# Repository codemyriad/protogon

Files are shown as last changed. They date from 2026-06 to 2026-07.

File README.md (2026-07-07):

# Protogon

The protogon is a prototyping board for the EMF Tildagon and Spaceagon badges.
If you don't understand what this means, it probably means that this project is not useful to you. But feel free to go down the rabbit hole!

* 64 kiB EEPROM
* EEPROM write protection jumper (P1) sort is write protected
* Qwiic connector
* I2c pull ups
* Power LED
* max 3v3 current: 600mA

Protogon, top side

It can be used to prototype a hexpansion. It features EEPROM (with write-protect jumper) and Qwiic connections.

The idea is based on JakeW's [protoboard hexpansion](https://www.tindie.com/products/jakew/protoboard-hexpansion/).

The board fits a 64 kbit EEPROM. There's a jumper you can short to write protect the EEPROM.
A connector is available to plug in Qwiic/STEMMA QT compatible sensors.

Even when not populated with components the board can be used for a basic hexpansion. The EEPROM is quite a valuable bit to mount, since the badge can recognize the hexpansion and load its code.

## Using files in the repo

The KiCad files are in the root: `codemyriad-protogon.kicad_*`.
The `fabrication/codemyriad-protogon-fab.zip` file is ready to upload to produce the board through a PCB manufacturing service. Make sure you select 1.0 mm FR4 and ENIG finish!
`fabrication/bom-lcsc.csv` contains a Bill Of Materials with LCSC codes.

## Credits

* Many thanks to **JakeW** for the [Protoboard Hexpansion](https://www.tindie.com/products/jakew/protoboard-hexpansion/). The idea for this board came from seeing his one.
* **EMF Camp** for the badge, the hexpansion spec, and the [KiCad template](https://github.com/emfcamp/badge-2024-hardware). This work is based on those KiCad files.

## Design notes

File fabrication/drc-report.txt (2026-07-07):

** Drc report for codemyriad-protogon.kicad_pcb **
** Created on 2026-07-07T11:46:43+0200 **
** Report includes: Errors **

** Found 0 DRC violations **

** Found 0 unconnected pads **

** Found 0 Footprint errors **

** End of Report **

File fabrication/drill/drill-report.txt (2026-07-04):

Drill report for codemyriad-protogon.kicad_pcb
Created on 2026-07-04T14:08:01+0200

Copper Layer Stackup:
    =============================================================
    L1 :  F.Cu                      front
    L2 :  B.Cu                      back

Drill file 'codemyriad-protogon-PTH.drl' contains
    plated through holes:
    =============================================================
    T1  0.300mm  0.0118"  (1 hole)
    T2  0.400mm  0.0157"  (9 holes)
    T3  0.400mm  0.0157"  (16 holes)
    T4  1.000mm  0.0394"  (140 holes)
    T5  1.200mm  0.0472"  (2 holes)
    T6  2.200mm  0.0866"  (2 holes)

    Total plated holes count 170

Drill file 'codemyriad-protogon-NPTH.drl' contains
    unplated through holes:
    =============================================================

    Total unplated holes count 0

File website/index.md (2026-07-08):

# A prototyping board to build your hexpansion

The protogon board

Features:

* 64 Kbit (8 KiB) EEPROM
* EEPROM write protection jumper (P1): short it to write-protect
* Qwiic connector
* I2C pull-ups
* Power LED
* max 3V3 current: 600 mA

## Parts to solder

* `R1`: one 402 Ω resistor
* `R2`, `R3` and `R4`: three 4.7 kΩ resistors
* `C1`: a 0.1 µF capacitor
* `D1`: an LED
* `U1`: a 64 Kbit EEPROM
* `U2`: a Qwiic connector

We missed a mark on the board. This is the correct LED polarity:

Close-up of D1: the bar of the diode symbol marks the cathode, on the GND side

## Online code editor for badge apps

We extended (vibe coded) the [badge emulator](https://emulator.badge.emfcamp.org/) and added a code editor.
[You can try live coding your badge app here](https://protogon.codemyriad.io/editor)

## Github repository

See https://github.com/codemyriad/protogon for source KiCad files and more

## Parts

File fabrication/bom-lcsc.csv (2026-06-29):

Designator | Footprint | Quantity | Value | LCSC Part #
C1 | 0603 | 1 | 0.1uF | C1591
D1 | 0805 | 1 | LED | C19171391
H1, H2 | MountingHole_2.2mm_M2_Pad_Via | 2 | MountingHole_Pad
J2 | PinHeader_2x10_P2.54mm_Vertical | 1 | Conn_02x10_Odd_Even | C492427
P1 | HDR-TH_2P-P2.54-V-M | 1 | PZ254V-11-02P | C492401
PROTO1 |  | 1 | integrated 10x14 protoboard grid
R1 | 0603 | 1 | 402 | C2930100
R2, R3, R4 | 0603 | 3 | 4K7 | C105428
U1 | TSSOP-8_L4.4-W3.0-P0.65-LS6.4-BL | 1 | ZD24C64A-XGMT | C2875852
U2 | CONN-SMD_4P-P1.00_SM04B-SRSS-TB-LF-SN | 1 | SM04B-SRSS-TB_(LF)(SN) | C160404

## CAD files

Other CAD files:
fabrication/step/codemyriad-protogon.step

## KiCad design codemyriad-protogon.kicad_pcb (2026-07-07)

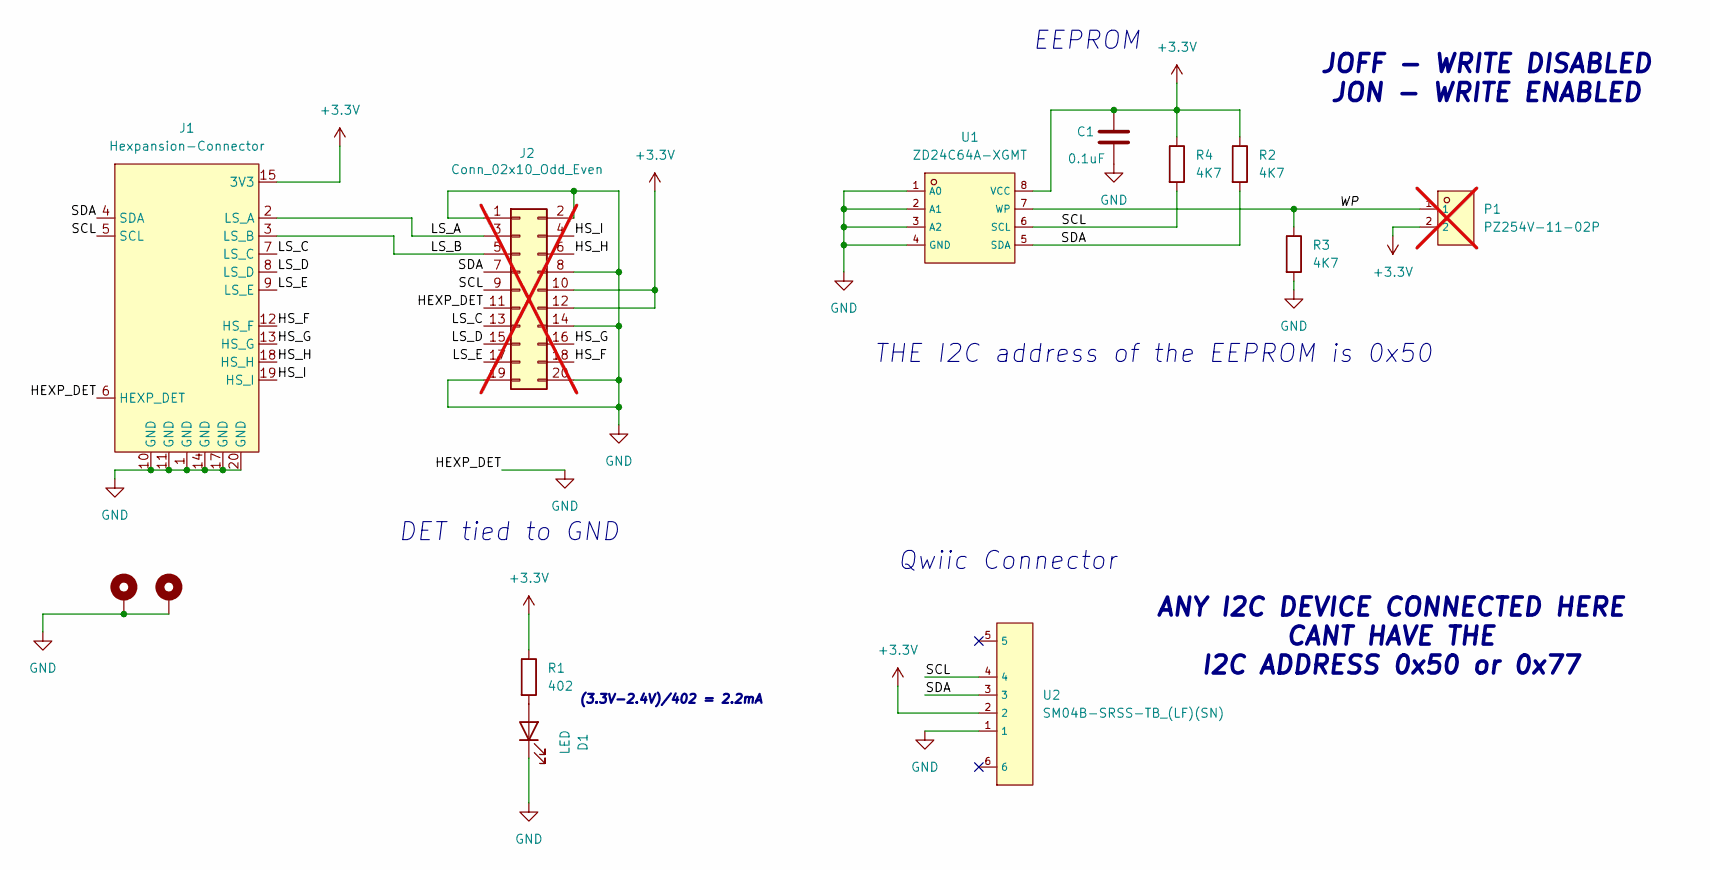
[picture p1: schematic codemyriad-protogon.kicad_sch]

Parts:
C1: 0.1uF; C_0603_1608Metric_Pad1.08x0.95mm_HandSolder; LCSC C1591
D1: LED; LED_0805_2012Metric; LCSC C19171391
H1, H2: MountingHole_Pad; MountingHole_2.2mm_M2_Pad_Via
J1: Hexpansion-Connector; hexpansion-edge-connector
J2: Conn_02x10_Odd_Even; PinHeader_2x10_P2.54mm_Vertical; LCSC C492427; not fitted
P1: PZ254V-11-02P; HDR-TH_2P-P2.54-V-M; LCSC C492401; not fitted
R1: 402; R_0603_1608Metric; LCSC C2930100
R2, R3, R4: 4K7; R_0603_1608Metric_Pad0.98x0.95mm_HandSolder; LCSC C105428
U1: ZD24C64A-XGMT; TSSOP-8_L4.4-W3.0-P0.65-LS6.4-BL; LCSC C2875852
U2: SM04B-SRSS-TB_(LF)(SN); CONN-SMD_4P-P1.00_SM04B-SRSS-TB-LF-SN; LCSC C160404

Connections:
+3.3V: C1.1, J1.15 (3V3), J1.16 (3V3), J2.10, J2.12, P1.2, R1.1, R2.1, R4.1, U1.8 (VCC), U2.2; also elsewhere on the board
/HS_F: J1.12 (HS_F), J2.18
/HS_G: J1.13 (HS_G), J2.16
/HS_H: J1.18 (HS_H), J2.6
/HS_I: J1.19 (HS_I), J2.4
/LS_A: J1.2 (LS_A), J2.3
/LS_B: J1.3 (LS_B), J2.5
/LS_C: J1.7 (LS_C), J2.13
/LS_D: J1.8 (LS_D), J2.15
/LS_E: J1.9 (LS_E), J2.17
/SCL: J1.5 (SCL), J2.9, R4.2, U1.6 (SCL), U2.4
/SDA: J1.4 (SDA), J2.7, R2.2, U1.5 (SDA), U2.3
/WP: P1.1, R3.1, U1.7 (WP)
GND: C1.2, D1.1 (K), H1.1, H2.1, J1.1 (GND), J1.6 (HEXP_DET), J1.10 (GND), J1.11 (GND), J1.14 (GND), J1.17 (GND), J1.20 (GND), J2.1, J2.2, J2.8, J2.11, J2.14, J2.19, J2.20, R3.2, U1.1 (A0), U1.2 (A1), U1.3 (A2), U1.4 (GND), U2.1; also elsewhere on the board
unnamed: D1.2 (A), R1.2

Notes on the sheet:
Qwiic Connector
(3.3V-2.4V)/402 = 2.2mA
DET tied to GND
EEPROM
JOFF - WRITE DISABLED JON - WRITE ENABLED
THE I2C address of the EEPROM is 0x50
ANY I2C DEVICE CONNECTED HERE CANT HAVE THE I2C ADDRESS 0x50 or 0x77

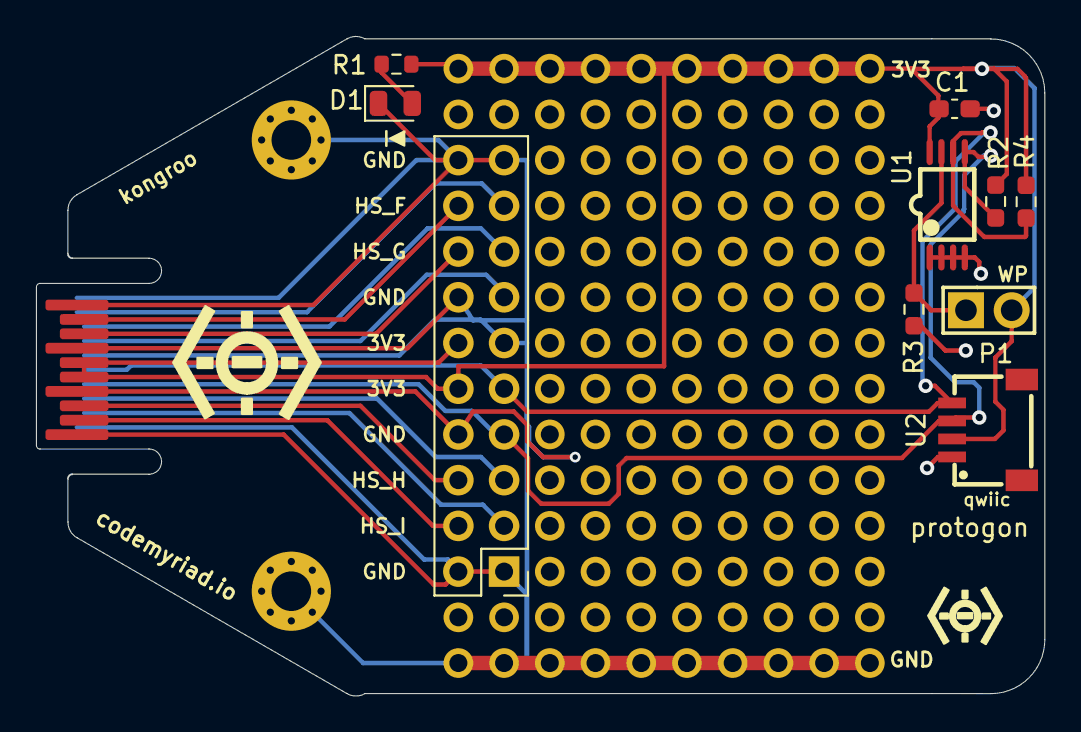
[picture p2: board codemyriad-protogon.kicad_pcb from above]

Board: 2 copper layers, 56.0 x 36.6 mm, 14 parts (0 on the bottom side), 15 nets.

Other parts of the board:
PROTO1: integrated 10x14 protoboard grid

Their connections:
+3.3V: PROTO1.1, PROTO1.2, PROTO1.3, PROTO1.4, PROTO1.5, PROTO1.6, PROTO1.7, PROTO1.8, PROTO1.9, PROTO1.10; also elsewhere on the board
GND: PROTO1.111, PROTO1.112, PROTO1.113, PROTO1.114, PROTO1.115, PROTO1.116, PROTO1.117, PROTO1.118, PROTO1.119, PROTO1.120; also elsewhere on the board

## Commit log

2026-06-22 Initial commit: Code Myriad Protogon hexpansion + order prep
    Bare protoboard hexpansion for the EMF 2024 Tildagon / 2026 Spaceagon badge,
    plus the cost research used to decide how/where to order the giveaway run.
    - codemyriad-protogon/: KiCad design (DRC clean), fabrication/ Gerber+drill
    order zip, STEP model, and renders
    - tools/: generate_protogon.py (generates the .kicad_pcb -- the source of
    truth) and render_protogon_blender.py
    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
    [codemyriad-protogon-B_Cu.gbl, codemyriad-protogon-B_Mask.gbs, codemyriad-protogon-B_Silkscreen.gbo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]
2026-06-22 Add Cycles GPU render path + one-command remote-render workflow
    Accurate, GPU-accelerated renders for the giveaway visuals.
    - render_protogon_blender.py: new --engine cycles (OptiX/CUDA path tracing on
    the GPU, auto backend selection with CPU fallback). Denoises with
    OpenImageDenoise by default because the OptiX denoiser fails to initialise on
    some driver/GPU combos (observed on RTX 5060 / Blackwell + Blender 4.5);
    path tracing still runs on the GPU. Adds per-engine sample defaults
    (8 eevee / 128 cycles), --gpu-backend, --denoiser, and --poster-only.
    - tools/render-on-roy.sh: rsync the repo to a GPU box, render the loop with
    Cycles/OptiX, and sync poster/MP4/GIF/contact back int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
2026-06-22 Audit follow-ups: fix width field + document board regeneration
    - QUOTE-RECIPE.json: correct outline_bbox width 48.0 -> 49.75 mm (the 48.0 omitted
    the J1 connector tab; 49.75 matches the fab-detected size both quotes used) and
    annotate why.
    - README: document the regenerate-from-clean prerequisites for the source-of-truth
    board -- the gitignored upstream clone (pinned) and KiCad's pcbnew module -- plus
    the generate + fab re-export steps.
2026-06-22 Regenerate loop renders with Cycles/OptiX (GPU, photoreal)
    Replaces the EEVEE turntable loop with a Cycles path-traced version rendered on
    the RTX 5060 (roy.wye.it): 96 frames, 1280x720, 128 spp, OpenImageDenoise.
    Accurate ENIG gold, matte black soldermask, and real shadows. Poster, MP4, GIF
    (stride-2 / 12.5 fps, judder-free) and contact sheet all regenerated.
2026-06-22 Render the real board geometry (truthful) instead of flat decals
    The loop was painting the artwork as self-lit 2D "decal" planes floating over a
    featureless slab, which made it untruthful: flat unlit gold, copper-vs-gold pad
    mismatch, fake holes, no thickness, a back face mis-oriented 90deg, and a squared
    hexagon corner. Switch to rendering the actual GLB geometry (copper/pads/vias/
    silkscreen/soldermask/body) with lit PCB materials, so it's one real 3D object.
    - render_protogon_blender.py: real ENIG gold (metallic, satin), semi-gloss black
    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
2026-06-22 Fix camera near-clip slicing the board; slow the loop to 8s
    - render_protogon_blender.py: set scale-relative ORTHO camera clip planes
    (clip_start = max_dim*0.1, clip_end = max_dim*10). The default 0.1m near clip
    was slicing whichever hexagon corner swung closest to the camera, which read
    as the board being clipped to a bounding cube. Verified clean at all angles.
    - Slow the turntable: default loop 96 -> 192 frames at 24 fps (4s -> 8s/rev),
    same smoothness; GIF stride-2 decimation stays exact (192 even). Updated the
    render-on-roy.sh default and the README loop math.
    - Regenerated poster/MP4/GIF/contact (192f, 1280x720, 128 spp, RTX 5060).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
2026-06-22 Add --xray render mode (translucent soldermask) to inspect copper routing
    On a real black-soldermask board the J1->J2 breakout traces are buried under the
    opaque mask and aren't visible -- only exposed gold pads and white silk show.
    --xray drops the soldermask to ~15% opacity so the copper routing shows through,
    for design inspection (not a truthful product shot). material() gains an `alpha`
    arg; apply_board_materials takes `xray`.
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2026-06-22 Real logo on both faces + photoreal render pipeline + EMF backdrop
    Logo:
    - Replace the placeholder mark with the real Code Myriad emblem, converted from
    the official codemyriad.io/logo.svg (tools/svg_logo_to_silk.py -> baked
    tools/codemyriad-logo.json, placed by generate_protogon.add_logo).
    - Put the emblem + codemyriad.io on BOTH faces, shifted into the connector wing
    (toward the edge connector, clear of the proto field). Move the J1 connector's
    TOP/BOTTOM/pin-1 silk text off the silkscreen to free the wing (orientation
    stays clear from the board shape + branding). DRC clean (0 violations).
    Render pipeline (per the PCB-render guide), for renders that gauge the real object:
    - Mate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
    [codemyriad-protogon-B_Cu.gbl, codemyriad-protogon-B_Mask.gbs, codemyriad-protogon-B_Silkscreen.gbo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]
2026-06-22 Fix: expose a solderable gold ring on every proto pad (mask openings)
    The 120 proto-grid pads had copper annular rings but NO soldermask aperture --
    make_pad() set the layer set to LSET.AllCuMask(), which (despite the name) is the
    copper layers only, so the black soldermask covered every ring. The proto field
    would have been unsolderable: a real defect, not a render artifact (spotted by
    comparing to JakeW's reference protohex where every hole has an exposed gold ring).
    Keep the PAD's default through-hole layer set instead (F/B copper + F/B mask
    apertures), so all 120 holes now expose a gold ENIG ring. DRC clean (0 violations).
    Regenerated fabrication (the F/B mask gerbers gain 120 openings)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
    [codemyriad-protogon-B_Cu.gbl, codemyriad-protogon-B_Mask.gbs, codemyriad-protogon-B_Silkscreen.gbo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]
2026-06-22 Clean up repo structure + rewrite READMEs (rationale, credits, badge links)
    The project now has a clear direction (the bare protoboard), so consolidate the
    experimentation:
    - Group business docs under docs/ (contractor brief, pricing, quote recipe).
    - Remove obsolete render assets: the decal textures (renders/texture/) and the dead
    decal-plane code path in render_protogon_blender.py (we render real geometry now);
    the superseded static renders (renders/top.png, bottom.png -> renders/kicad/); and the
    stale X-ray loop (renders/blender-xray/, regenerable via XRAY=1).
    - Drop stray DRC reports, fp-info-cache, and KiCad backups; gitignore *.rpt.
    - Regenerate the loop renders (gold-ring fix +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
2026-06-23 qwiic-experiment: add Qwiic+EEPROM hexpansion review brief + design files
    Review brief (README) for an external PCB designer to validate, improve, and
    finalize the Qwiic + EEPROM hexpansion variant before ordering, plus the KiCad
    design, hand-authored parts list, AI review/de-risk appendices, and renders.
    [codemyriad-protogon-qwiic-bom.csv, codemyriad-protogon-qwiic.kicad_pcb, codemyriad-protogon-qwiic.kicad_sch]
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2026-06-23 qwiic-experiment: add Tildagon/hexpansion background primer; correct README fab spec
    Dense primer for PCB reviewers new to the Tildagon: edge-connector pinout, mechanical
    rules (1mm + ENIG mandatory, hextended envelope, 7mm height zone, copper-to-edge),
    per-slot isolated I2C with no badge pull-ups, the identify-EEPROM mechanism, Qwiic
    pinout, fab gotchas, and verified primary-source links (mined from the EMF badge team
    chat history + official docs/firmware). Link it from the README and fix the fab spec:
    1.0mm thickness and ENIG are hexpansion requirements, not cost-revisitable settings.
2026-06-25 qwiic-experiment: rewrite brief to be concise, expert-facing, and point at the base board
    README and REVIEW-HANDOFF were too verbose and spoke past experts. Rework both:
    - lead with the actual task: the LLM did a poor job placing the ear + EEPROM
    block; placing these well is the core ask
    - tell the reviewer up front to start from ../codemyriad-protogon.kicad_pcb
    (the trusted base board), not this folder's LLM attempt
    - add prominent links to the official hexpansion guide and badge-2024-hardware
    template, and embed the 1:1 paper fit template SVG
    - correct the stale 'bus unrouted' claim in REVIEW-HANDOFF (the LLM board
    does route it; continuity is what's unverified)
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2026-06-29 Final board with EEPROM and connector
    [bom.csv, designators.csv, positions.csv]
2026-06-30 Promote the EEPROM + Qwiic board; archive the prototype; KiCad renders
    The human-finalized board (I2C identify EEPROM + Qwiic/STEMMA QT connector,
    4K7 pull-ups, a black 1.0mm ENIG hexpansion) is now the one prominent design,
    flattened out of the nested codemyriad-protogon/ subdirectory to the repo root.
    - Flatten the board and its libraries to the repo root
    - Archive the original bare-protoboard prototype, the generate_protogon.py
    generator, and the Blender render pipeline + assets under archive/
    - Delete the qwiic-experiment/ commissioning brief and the rejected LLM draft
    - Regenerate all fabrication outputs in parity (gerbers, drill, STEP,
    positions, fresh DRC report: 0 errors, 0 unco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
    [BOM_300boards_mouser.csv, bom.csv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]
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2026-06-30 Rework the P1 jumper so it write-protects the EEPROM
    P1 pin 2 now goes to +3V3 instead of GND, so shorting the jumper pulls WP
    high and write-protects the EEPROM after provisioning. R3 still pulls WP low,
    so the part is writable by default for the badge to provision. Board files
    from the designer's reworked version.
    - Update .kicad_pcb / .kicad_sch (reworked P1 net + routing)
    - Regenerate fabrication outputs (gerbers, drill, STEP, DRC: 0 errors, 0 unconnected)
    - Re-render top/bottom/perspective with P1 shown, now that it's functional
    - README: document short-P1-to-write-protect
    [codemyriad-protogon-B_Cu.gbl, codemyriad-protogon-B_Mask.gbs, codemyriad-protogon-B_Silkscreen.gbo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]
2026-06-30 Route the Qwiic VCC; board is DRC/ERC clean and order-ready
    The designer routed the one remaining track (U2 pin 2 → +3.3V), closing the
    Qwiic-power bug from the review. Board files are from their KiCad save;
    fabrication outputs and renders regenerated to match.
    - U2.2 Qwiic VCC now on +3.3V and routed: DRC 0 errors, 0 unconnected
    - ERC clean; no orphan nets
    - Re-verified vs spec: edge-connector pinout (all 20), EEPROM at 0x50,
    SDA/SCL, 4K7 pull-ups, WP jumper, decoupling, detect→GND
    - Regenerate gerbers, drill, STEP, positions, DRC report, renders
    [codemyriad-protogon-B_Cu.gbl, codemyriad-protogon-B_Mask.gbs, codemyriad-protogon-B_Silkscreen.gbo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]
2026-06-30 Tidy the +3.3V feed routing; regenerate outputs
    Updated board files from the designer: a small cleanup of the +3.3V feed
    routing near the top of the board (no connectivity change). Re-verified and
    regenerated to match.
    - Connectivity byte-identical to the previous version (no net changed)
    - DRC 0 errors / 0 unconnected, ERC clean, no orphan nets
    - Production-readiness once-over (electrical, DFM under JLCPCB rules,
    footprints, outline/BOM): no issues; outline + mouth slot + edge fingers
    + BOM all check out
    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
    [codemyriad-protogon-B_Cu.gbl, codemyriad-protogon-B_Mask.gbs, codemyriad-protogon-B_Silkscreen.gbo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]
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2026-07-01 Remove clutter
    [codemyriad-protogon.kicad_pcb, codemyriad-protogon.kicad_sch]
2026-07-01 Include pointers to useful files in the repo
    [BOM_300boards_mouser.csv, bom-lcsc.csv]
2026-07-01 Fix missing surface components from rendering
    [codemyriad-protogon.kicad_pcb, codemyriad-protogon.kicad_sch]
2026-07-02 Rotate text
    [codemyriad-protogon.kicad_pcb]
2026-07-04 Silkscreen cleanup, green soldermask; regenerate production files
    Silkscreen:
    - Remove the stray '+' near the edge connector and the 'v1' under 'protogon'
    - Add 'WP' above the P1 write-protect jumper and 'qwiic' under U2
    - Center the small hex logo (both faces) between the hole grid and board edge
    - Hide the PROTO1 reference that plotted at the origin, far off-board
    Soldermask changes from black to standard green (#0E6B2E in the stackup
    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
    [codemyriad-protogon-B_Cu.gbl, codemyriad-protogon-B_Mask.gbs, codemyriad-protogon-B_Silkscreen.gbo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]
2026-07-04 Make the WP jumper label legible
    The WP label sat right under the EEPROM pins and read as part of U1.
    Move the R2/R4 designators to the other side of their resistors and
    put WP in the freed corner directly above the jumper; P1 goes back
    under the jumper at full size. Silkscreen-only change: all other
    gerber layers verified byte-identical, DRC clean. Renders refreshed.
    [codemyriad-protogon-B_Cu.gbl, codemyriad-protogon-B_Mask.gbs, codemyriad-protogon-B_Silkscreen.gbo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]
2026-07-04 Snug the WP label against the jumper
    Lower WP so it sits directly on the jumper outline instead of floating
    halfway to the EEPROM; shifted right to clear the via. Front silk only:
    all other gerber layers byte-identical, DRC clean. Renders refreshed.
    [codemyriad-protogon-B_Cu.gbl, codemyriad-protogon-B_Mask.gbs, codemyriad-protogon-B_Silkscreen.gbo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]
2026-07-04 Add 'kongroo' to the top silkscreen
    Lowercase, bold, 30° along the top-left chamfer — the front-side twin
    of 'protogon' on the bottom face (same anchor, size and slant). Front
    silk only: all other gerber layers byte-identical, DRC clean. Fab zip
    and renders regenerated.
    [codemyriad-protogon-B_Cu.gbl, codemyriad-protogon-B_Mask.gbs, codemyriad-protogon-B_Silkscreen.gbo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]
2026-07-07 Add LED polarity marking to D1; regenerate production files
    Add a standard diode symbol (triangle pointing at the cathode bar) on
    the front silkscreen below D1; the bar sits on pad 1 (K, GND). Drawn in
    the footprint instance so it follows the part.
    Regenerated fabrication outputs and renders. Verified against the
    previous files: copper, masks, edge cuts, drills and positions are
    byte-identical; only F_Silkscreen gained the new symbol. DRC clean.
    [codemyriad-protogon-B_Cu.gbl, codemyriad-protogon-B_Mask.gbs, codemyriad-protogon-B_Silkscreen.gbo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]
2026-07-08 Website: fix part values/units, add LED polarity photo, generated index.html
    index.md fixes vs the BOM: R1 is 402 ohm (was '1 420 ohm'), R2-R4 are
    4.7k (was 42k), C1 is 0.1uF (was 10uF), EEPROM is 64 Kbit not 64 KiB,
    Qwiic connector designator is U2 not Q1; spelling and unit cleanup.
    Reference website/diode-mark.png showing the correct LED polarity.
    index.html is hand-generated from index.md; deployed to
    protogon.codemyriad.io (bunny storage + cache purge).
2026-07-08 website: add board render to the front page
    Store top.png as a real file (was a symlink into the untracked
    renders/ directory, which would be broken on clone).
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2026-09-27 Add top solder paste gerber for ordering an SMT stencil
    The fabrication outputs had no paste layer, so a stencil could not be
    made correctly from them. The paste layer is extracted from the SMD pad
    flashes in F_Cu (paste margin is zero on all pads), excluding the
    edge-connector fingers, which have no paste. 26 pads total.
    Claude-Session: https://claude.ai/code/session_014Ks4qa14qQu4TKMAzSfALr

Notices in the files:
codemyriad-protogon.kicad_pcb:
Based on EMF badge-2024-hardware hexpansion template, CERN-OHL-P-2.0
